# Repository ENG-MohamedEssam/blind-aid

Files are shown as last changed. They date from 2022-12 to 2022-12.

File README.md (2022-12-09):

# blind-aid

## Abstract 

#### This project was mainly split into two parts, the first one is using machine learning to identify 80 different objects and the code was working properly on the laptop and for future intentions i was going to move it to work on raspberry pi.
#### The second part was using small microcontroller to make the device cheaper and easy to aquire by many people, this part was meant to replace the stick that the blind would use by a small ring to wear in your hand.

## What are the components of the ring ?
#### mainly it has it's controller which is Atmega328p, A small potentiometer, a dip switch, a vibration motor like the ones in the mobile phones, and a laser sensor (VL53L0X Time of Flight Sensor) which has up to 2m percison distance

## How does the ring work?

#### The ring turns on/off using a switch when you point it to a rigid object it gives a sense of vibration to your hand and when you get closer to the object the ring vibrates even more and that gives you the sense of how close the object is to your hand.
### Note that  #### You can adjust the sensetivity of the device using the small potentiometer that's on the ring

#### I designed the ring on SolidWorks as you can see below
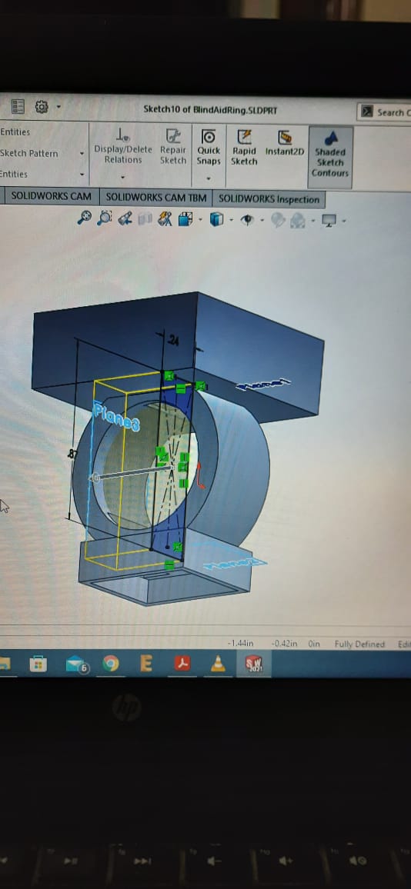
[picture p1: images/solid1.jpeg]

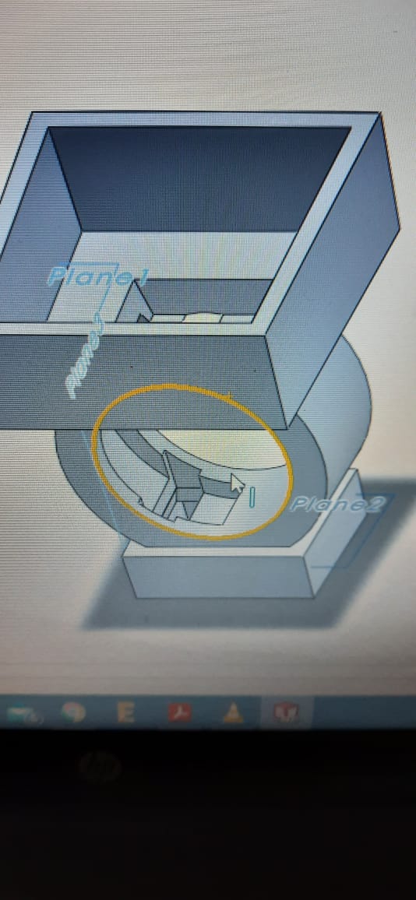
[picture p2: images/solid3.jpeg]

#### The board should take the top of the ring as it's housing and the bottom of the ring is meant for the laser sensor
#### I 3D-printed the ring as you can see below
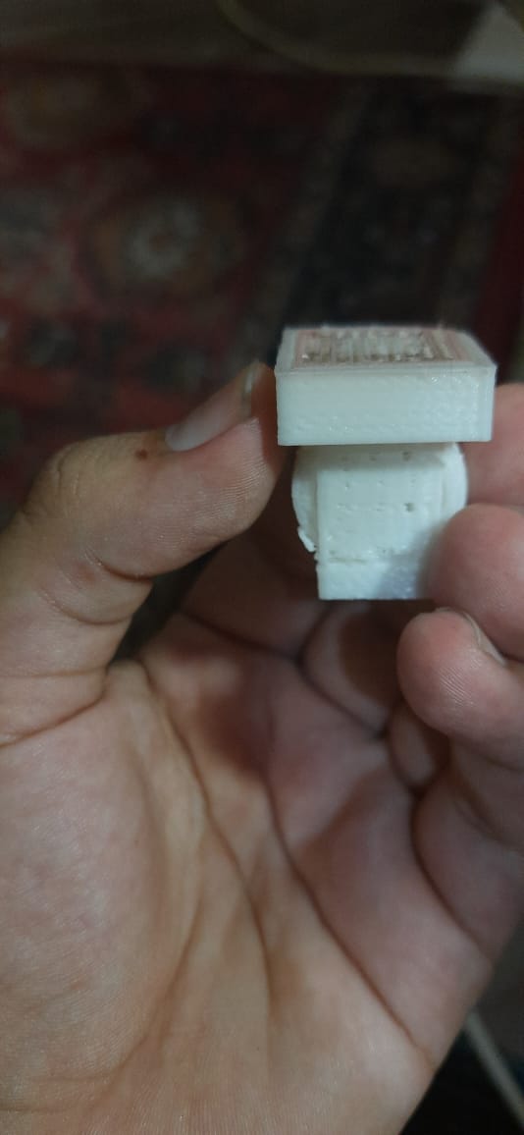
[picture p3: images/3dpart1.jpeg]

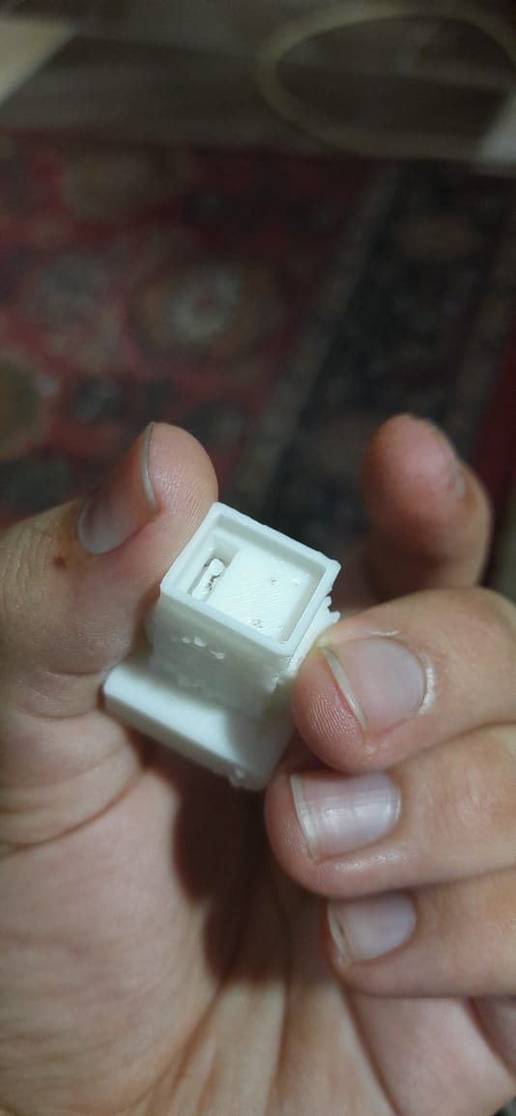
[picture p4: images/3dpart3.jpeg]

#### And the follwing is the design of the board
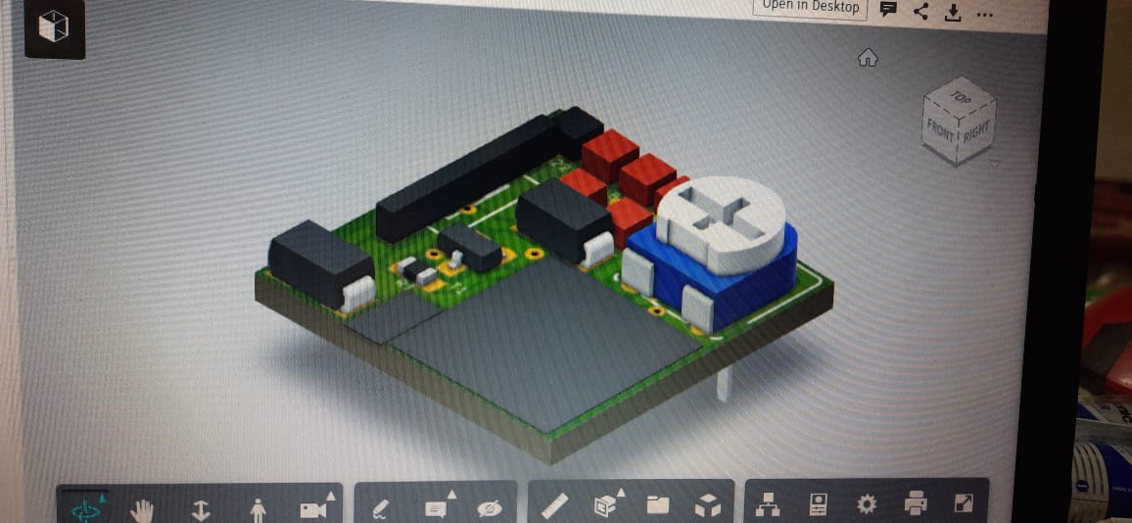
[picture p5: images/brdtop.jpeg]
top

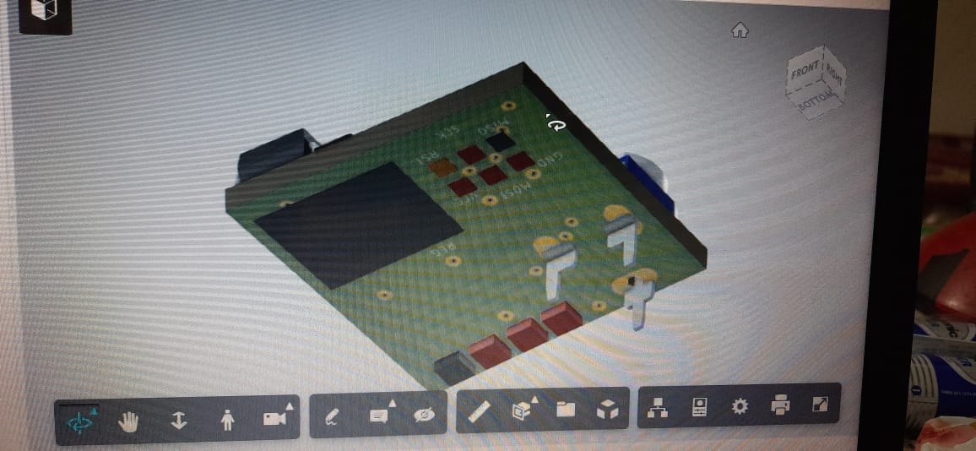
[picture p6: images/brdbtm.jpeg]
bottom

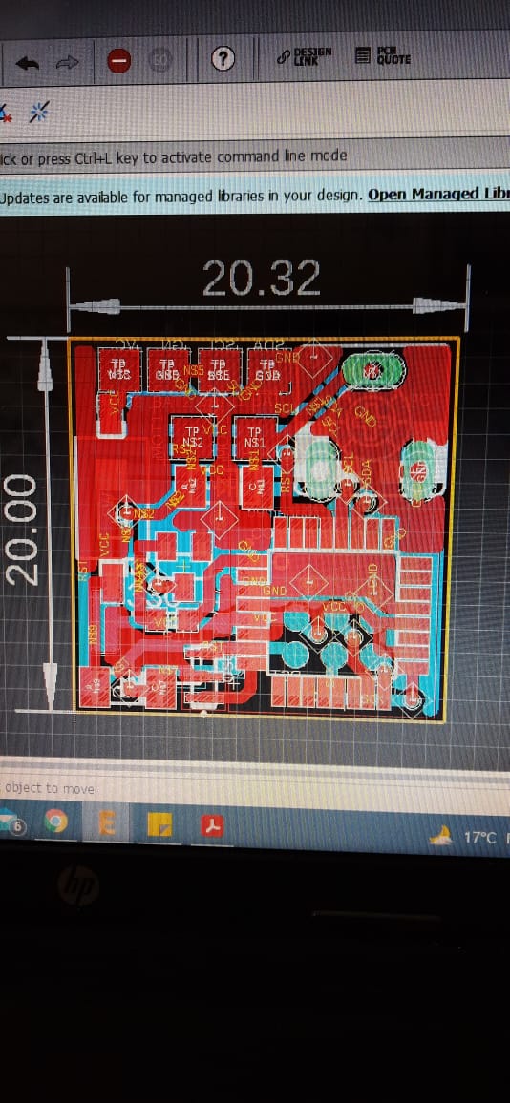
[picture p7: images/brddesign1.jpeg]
pcb1

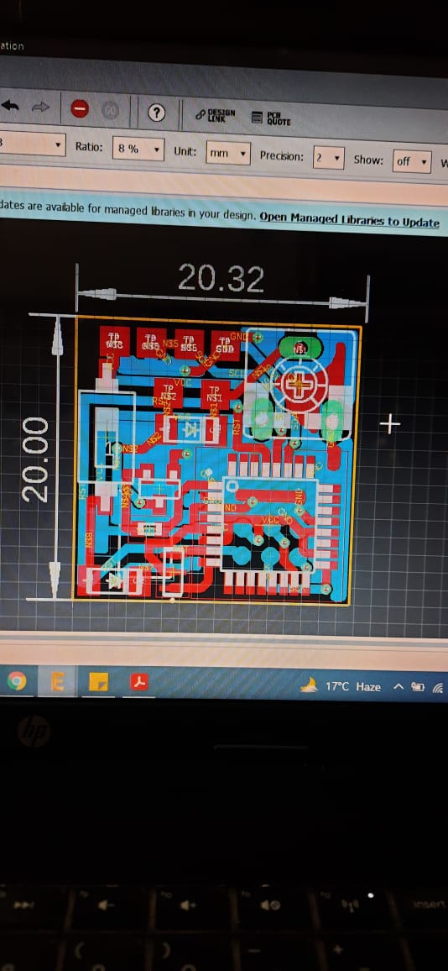
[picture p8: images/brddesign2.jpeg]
pcb2

#### The ring worked perfectly on a breadboard and for future intentions the board will be made and the product will be finished soon.

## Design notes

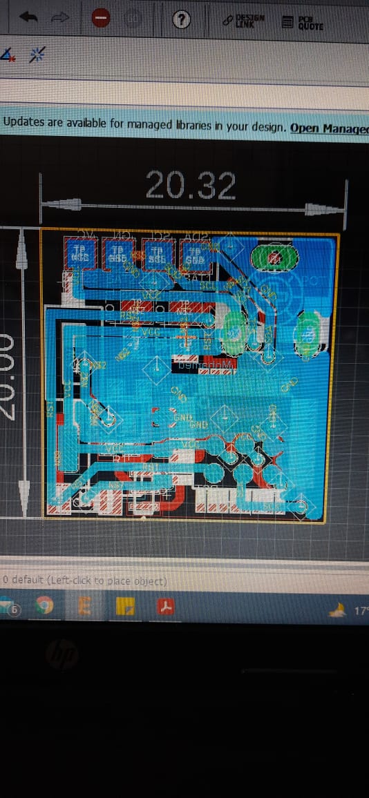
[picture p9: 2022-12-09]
images/brddesign3.jpeg

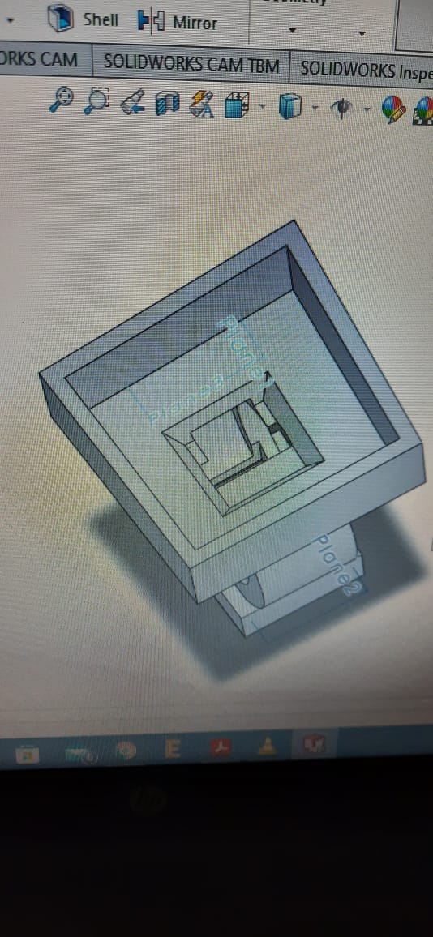
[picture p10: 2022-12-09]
images/solid2.jpeg

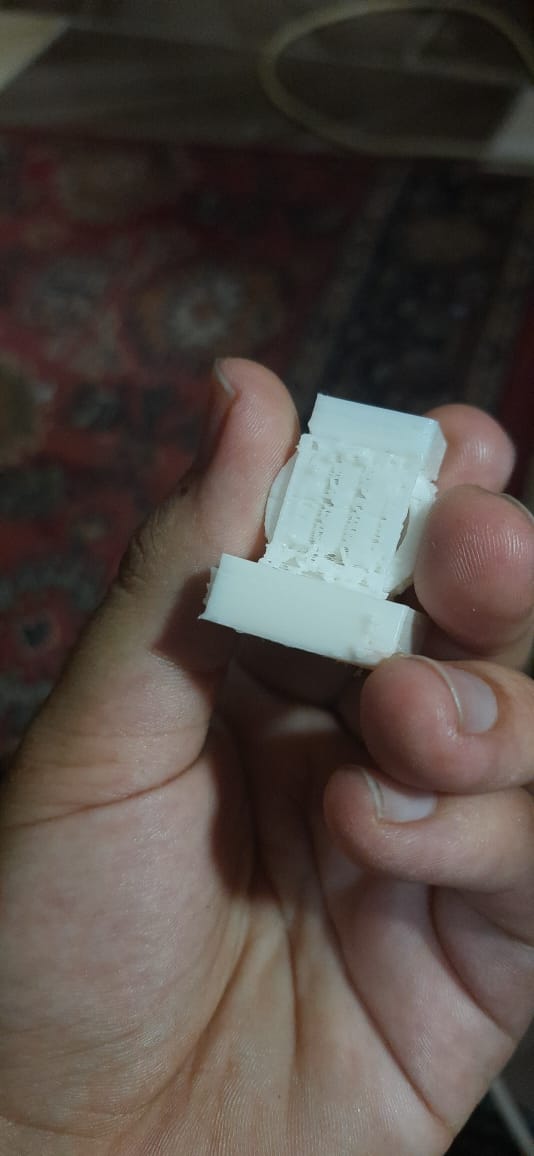
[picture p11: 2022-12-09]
images/3dpart2.jpeg

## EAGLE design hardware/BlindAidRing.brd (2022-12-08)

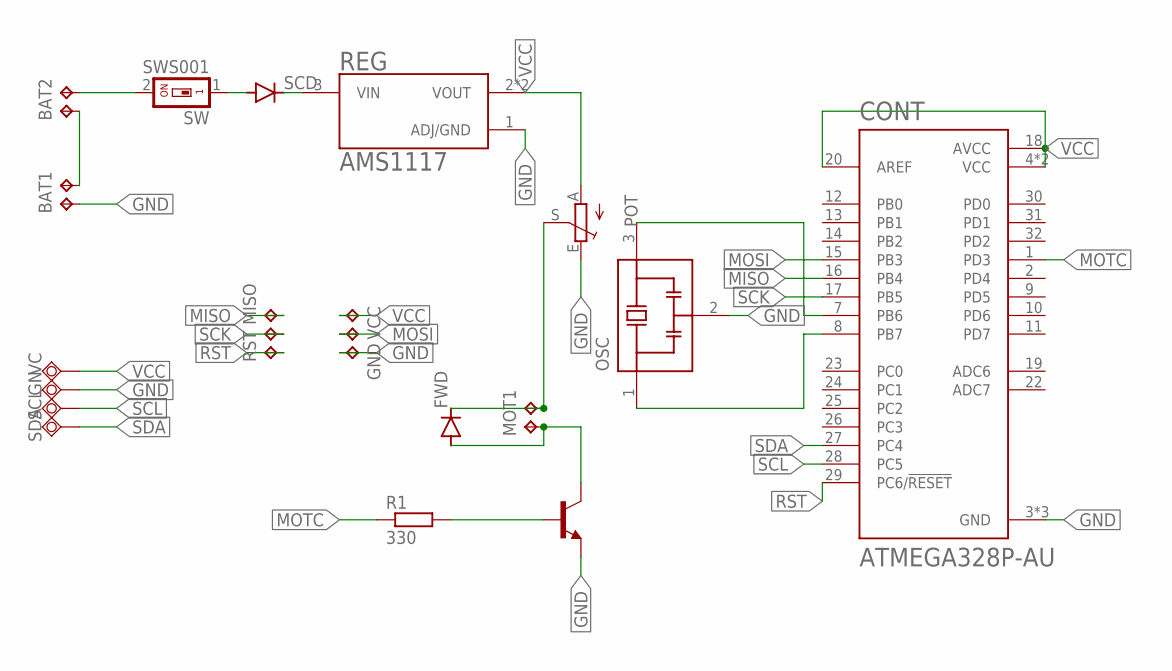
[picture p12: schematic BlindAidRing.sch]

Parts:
BAT1, BAT2, BAT11, BAT22: TPTP20SQ; TP20SQ
CONT: ATMEGA328P-AU; QFP80P900X900X120-32N
FWD: CGRM4002-G; SOD-123_MINI-SMA
GN: TPSQTP18SQ; TP18SQ
GND: TPB1,27; B1,27
MISO: TPB1,27; B1,27
MOSI: TPB1,27; B1,27
MOT1, MOT2: TPTP20SQ; TP20SQ
OSC: CSTCE16M0V53-R0; OSC_CSTCE16M0V53-R0
POT: TRIM_EU-CA6V; CA6V
R1: 330; R0603
REG: AMS1117; SOT229P700X180-4N
RST: TPB1,27; B1,27
SCD: CGRM4002-G; SOD-123_MINI-SMA
SCK: TPB1,27; B1,27
SCL: TPSQTP18SQ; TP18SQ
SDA: TPSQTP18SQ; TP18SQ
SW: SWS001; SMS-001
T1: -NPN-SOT23-EBC; SOT23-EBC
VC: TPSQTP18SQ; TP18SQ
VCC: TPB1,27; B1,27

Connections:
GND: BAT1.TP, CONT.3 (GND), CONT.5 (GND), CONT.21 (GND), GN.TP, GND.TP, OSC.2 (GND), POT.E, REG.1 (ADJ/GND), T1.E
MISO: CONT.16 (PB4), MISO.TP
MOSI: CONT.15 (PB3), MOSI.TP
MOTC: CONT.1 (PD3), R1.1
unnamed: FWD.C, MOT2.TP, POT.S
unnamed: FWD.A, MOT1.TP, T1.C
unnamed: BAT22.TP, SW.2
unnamed: R1.2, T1.B
unnamed: BAT2.TP, BAT11.TP
unnamed: REG.3 (VIN), SCD.C
unnamed: SCD.A, SW.1
unnamed: CONT.7 (PB6), OSC.3 (OUT)
unnamed: CONT.8 (PB7), OSC.1 (IN)
RST: CONT.29 (PC6/!RESET), RST.TP
SCK: CONT.17 (PB5), SCK.TP
SCL: CONT.28 (PC5), SCL.TP
SDA: CONT.27 (PC4), SDA.TP
VCC: CONT.4 (VCC), CONT.6 (VCC), CONT.18 (AVCC), CONT.20 (AREF), POT.A, REG.2 (VOUT), REG.4 (VOUT), VC.TP, VCC.TP

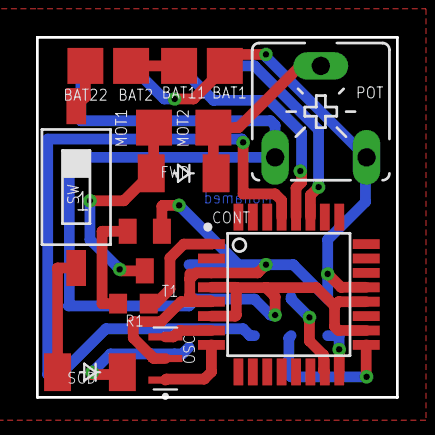
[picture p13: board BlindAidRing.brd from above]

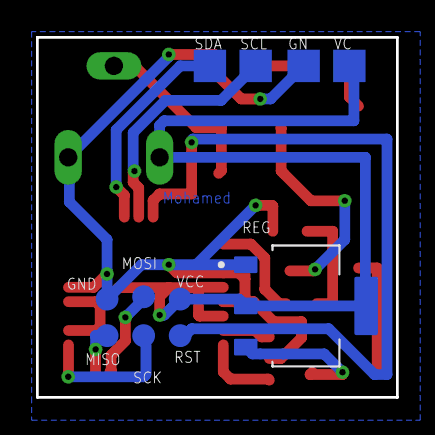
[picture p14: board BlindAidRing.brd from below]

Board: 2 copper layers, 20.0 x 20.0 mm, 25 parts (11 on the bottom side), 18 nets.

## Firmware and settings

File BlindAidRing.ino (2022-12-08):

#include "Adafruit_VL53L0X.h"

Adafruit_VL53L0X lox = Adafruit_VL53L0X();
#define VibMotor  3

int Val = 0;

void setup() {
  Serial.begin(115200);
  pinMode(VibMotor, OUTPUT);
  // wait until serial port opens for native USB devices
  while (! Serial) {
    delay(1);
  }
  
  //Serial.println("Adafruit VL53L0X test");
  if (!lox.begin()) {
    Serial.println(F("Failed to boot VL53L0X"));
    while(1);
  }
  // power 
  Serial.println(F("VL53L0X API Simple Ranging example\n\n")); 
}


void loop() {
  VL53L0X_RangingMeasurementData_t measure;
  Serial.print("Reading a measurement... ");
  lox.rangingTest(&measure, false); // pass in 'true' to get debug data printout!

  if (measure.RangeStatus != 4) {  // phase failures have incorrect data
    Serial.print("Distance (mm): "); Serial.println(measure.RangeMilliMeter);
    Val = map(measure.RangeMilliMeter, 30, 1200, 255, 0);
    analogWrite(VibMotor, Val);
  } else {
    Serial.println(" out of range ");
  }
    
  delay(100);
}
